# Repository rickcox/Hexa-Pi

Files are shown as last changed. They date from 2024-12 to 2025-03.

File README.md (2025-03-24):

# Hexa-Pi
A Compact 6 Compute Module Cluster

This is a PCB based project to create a very compact cluster of
Raspberry Pi CM4 compatible compute module boards.  It is quite bare-bones
in terms of peripheral support.  One of the modules - Module 5 - has a basic set of peripherals.
The other Modules - 0-4 - have only a small external connector for all I/O.
All 6 modules attach to a 1Gbit ethernet switch IC, which also has 2 off-board connectors.

It should be emphasized that **Compact Compute Cluster** is the focus of this design, not connectivity.
Connectivity, and peripheral support, has been reduced to meet the compact compute cluster goal.
Since all low voltage power, and the ethernet switch are on-board, a cluster of 6 Compute modules
can be supported with 1 12V DC power jack and 1 ethernet cable.
A 6 amp or larger 12V supply is recommended to support 6 running modules.

In addition, there are 2 external ethernet switch connectors, allowing boards to be "daisy chained".

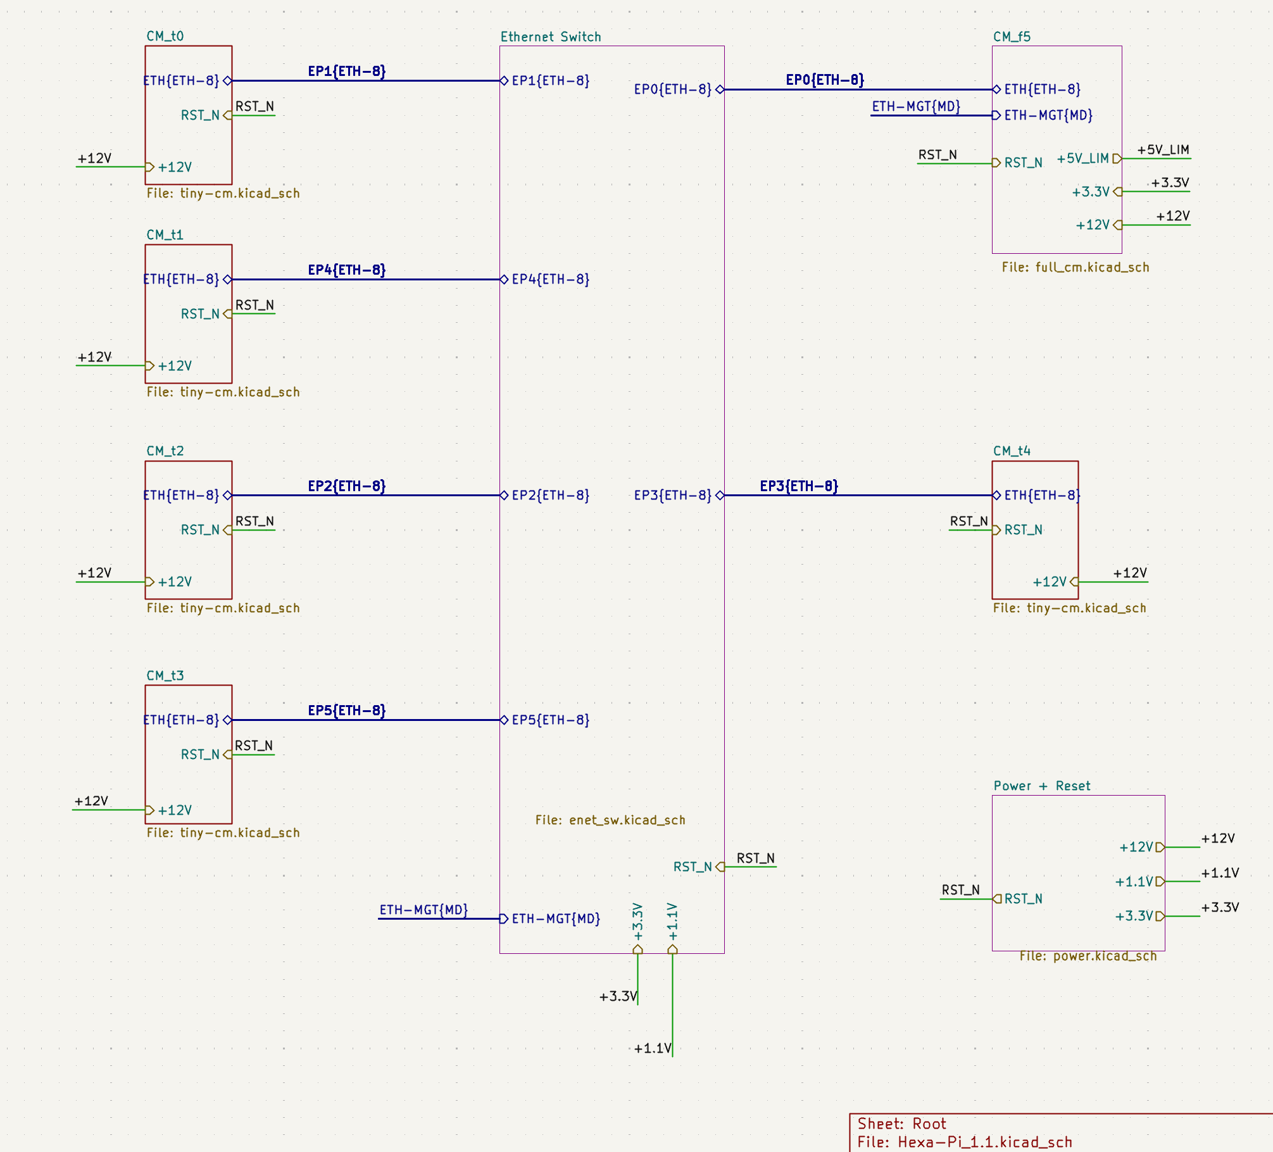
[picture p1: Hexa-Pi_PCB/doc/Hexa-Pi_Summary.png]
A simple overview


The PCB is 150mm X 150mm X 1.6mm.  

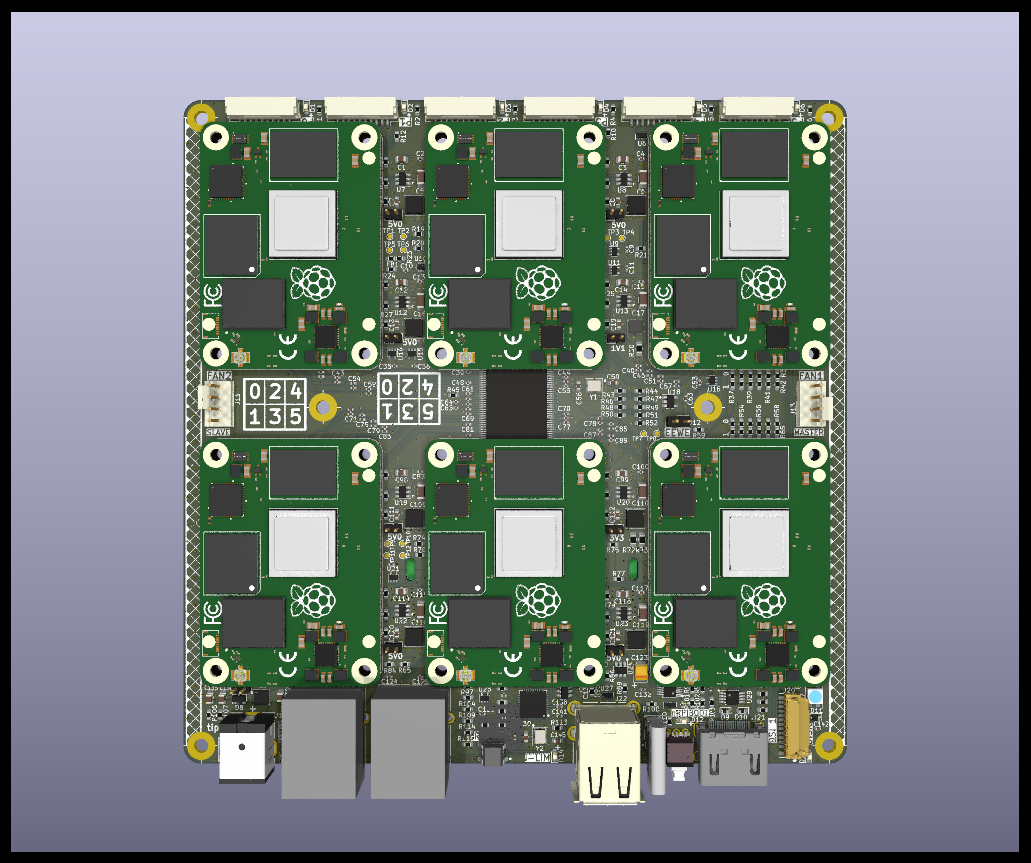
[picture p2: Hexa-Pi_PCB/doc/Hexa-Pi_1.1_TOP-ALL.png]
A View of the Hexa-Pi Board with 6 Pi CM4's installed


A goal of this design is to be as Compute Module independent as possible, to allow
for a variety of compatible modules to be used.  Several of the Compute Module compatible
boards have been tested:

- Raspberry Pi Compute Module 4:
  This board basically defigned the standard, so everything possible works on a Pi CM4.
  CM4 boards in the Module5 location may be either "Lite" or with EMMC.
  CM4 boards in the Module0-4 locations must have EMMC.
  
- Pine64 SOQuartz:
  This RK3566 base board works well. 
  Rockchip processors for some odd reason must use 1.5Mbps on the serial console.  
  The pluggable EMMC modules makes setup of these boards very easy if you buy a cheap EMMC-microSD converter.

- Banana Pi CM4:
  This Amlogic A311D based board is a bit faster than the Raspberry Pi CM4.
  These are a bit fussy to get setup, and OS selection is quite limited.

- Radxa CM5:
  This RK3588 based board is **very** fast, if that is what you are looking for.
  There are "Lite" and "Full" versions of this board. Only he Full has been tested, but both should work.
  Use caution that the extra 3rd connector does not make contact with the Hexa-Pi PCB components.
  Again, Rockchip processors use 1.5Mbps on the serial console.
  OS selection is also limited here.
  Due to higher power consumption, a larger heatsink is recommended for the Radxa CM5.

- Raspberry Pi Compute Module 5:
  **Testing TBD.**
  Not sure if serial port will work.
  The CM5 fan support is not compatible with CM4 or Hexa-Pi. The I2C fan controller can be used,
  as with a CM4

- Due to higher power consumption, a larger heatsink and possibly a heatspreader is recommended for the Raspberry Pi CM5.

Not all "compatible" boards have been tested.  
It is expected, unless the manufacturer has done something specific to make it incompatible, most "compatible" boards should work. 
Reviewing the datasheet and pinout on the 100 pin mezzanine connectors can be useful in spotting incompatibilities.

The Raspberry Pi CM4 boards have been most throughly tested.  
The other boards all have been verified to operate and connect via etherent, but all of the ports have not been tested.
Where known, incompatibilities have been noted.
It is recommended to initially configure an unfamiliar Compute Module in a Raspberry Pi CM4 IO board,
or board vendor specific baseboard, where all of the IO ports are available.
The Module5 location on the Hexa-Pi board may work for this, since it has USB, HDMI, and microSD
card support - but does not have the 40pin IO connector. 
Having a GUI is often helpful for the initial OS setup on a new board - even if your eventual use is headless.

Also, there is a small "Pi-Panel" support board that attaches to the external connectors 
at the top to provide a few simple peripherals for **all** of the Modules individually. 
A Green activity LED for each module is visible at the top, next to that module's connector.

There are also a Red power LED, a Yellow USB Overload LED, a White rpibboot mode LED, and a Blue NVME activity LED,
all on the main PCB, bottom edge.

Also included is stl files for a case for the Hexa-Pi board.
The PCB's were built, and mostly assembled, by JLCPCB.
The Case was 3D Printed. 

There is more information in the sub-directories:

- Main Hexa-Pi PCB
- Case for Hexa-Pi
- Pi-Panel PCB

This work is licensed under the Creative Commons Attribution 4.0 International License. To view a copy of the license, visit https://creativecommons.org/licenses/by/4.0/

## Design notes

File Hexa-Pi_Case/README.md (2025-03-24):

# Hexa-Pi
A Case for the Hexa-Pi board.

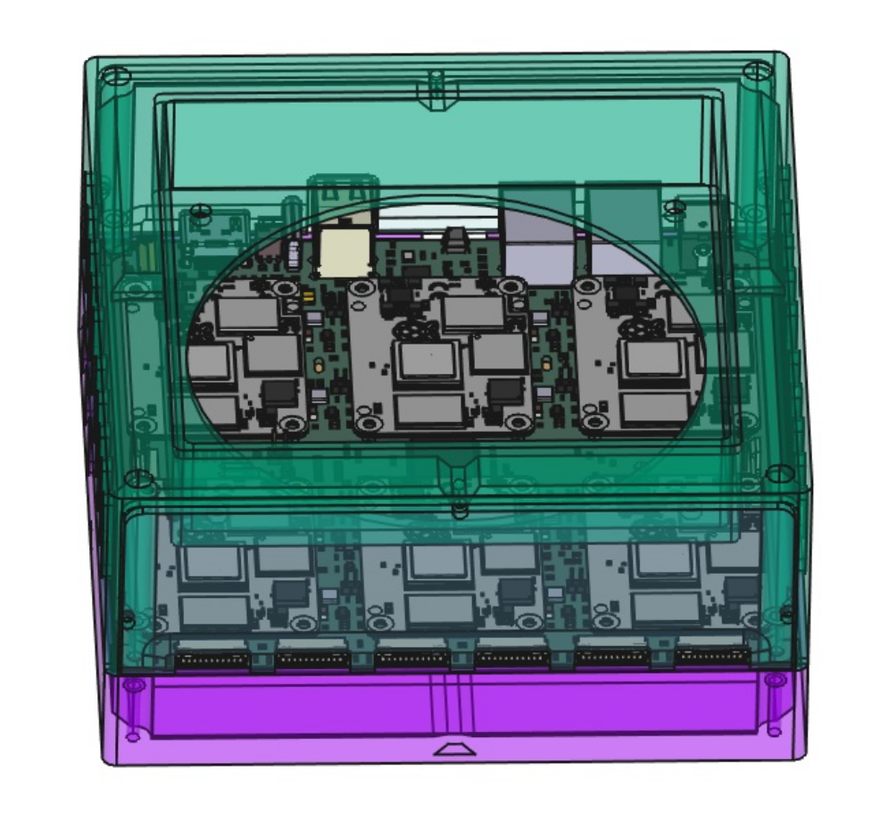
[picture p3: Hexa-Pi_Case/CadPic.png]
CAD Picture


Cases Stacked:

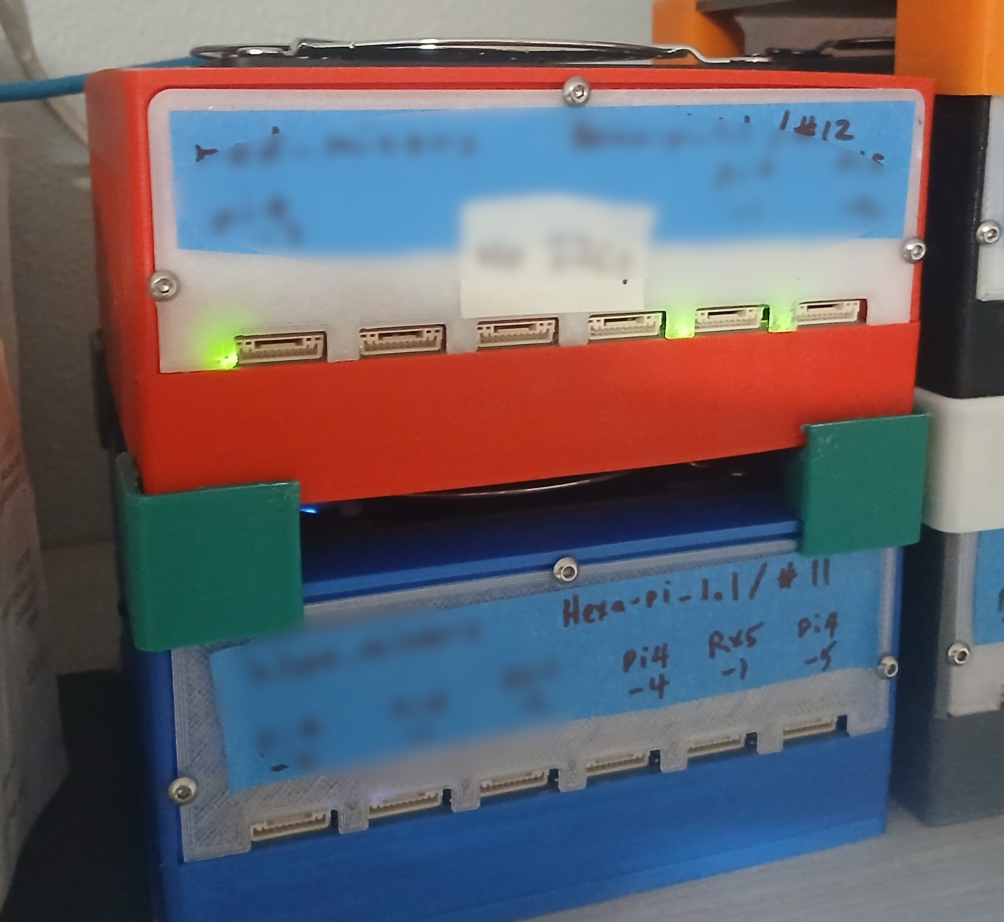
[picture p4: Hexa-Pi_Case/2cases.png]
Stacked Picture


This is a fairly simple case for the Hexa-Pi board.
It consists of 4 parts:
- A bottom
- A top - with the PCB connector ends fully exposed
- A Front Panel - this has cutouts for the 6 external connectors
  It is recommended to make this out of semitransparent material so the
  LEDS are readily visible
- A Back Panel - This has cutouts for the power, ethernet, USB and HDMI connectors.
  It is recommended to make this out of semi-transparent material so the
  LEDS are readily visible

In addition, there is a small standOff. 4 of these can be used for stacking.

For good airflow, a 120MM fan is inset on the top, and ventilation slots are on the sides.
The top fan location makes the case larger but provides good airflow without alot of sound,
and allows stacking of Hexa-Pi's. 
120MM fans can be run at around 1/2 speed, and still provide adequate cooling.

Additional hardware needed to assemble 1 board and case:
- 6 M3 heatset fittings. These are heat-set into the bottom - 2 near the center to
  hold the PCB from flexing, and 4 on the corners to secure the top.
- 6 10MM M3 bolts - 2 to hold the PCB, and 4 to secure the case top to the PCB and bottom
  Hex head bolts rather than Phillips head is preferred, since they are deeply inset.
  The 4 corners are difficult to access due to being deeply inset - SORRY!
- 6 4MM M3 bolts or tapered screws to hold the front and back panels on.
  These interfere with, and must be installed after (and removed before) the M3 corner bolts.
- A 120MM X 120MM fan with a 4 pin PWM connector.
  A fan which includes a finger guard/screen is recommended for safety.
  If the fan has a long lead, either wrap it around the fan side or zip-tie to the case.
- M5 bolts are usually provided with fans to hold the fan in place.
  Insert these bolts from inside the case and thread into the fan housing before assembling the case.

The long, deeply inset corner screws are very clumbsy to work with.
They make the case time consuming to assemble and dis-assemble.
Also the attachment of the front and back panels could be greatly improved.
**I would love some sort of snap on case, but my mechanical CAD skills are not there yet!**
**HINT, HINT!**

This work is licensed under the Creative Commons Attribution 4.0 International License. To view a copy of the license, visit https://creativecommons.org/licenses/by/4.0/

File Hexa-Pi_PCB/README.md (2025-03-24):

# Hexa-Pi_PCB
A Compact 6 Compute Module Cluster PCB

Here are some views of the PCB.
More are available in the doc folder.

Top view of PCB
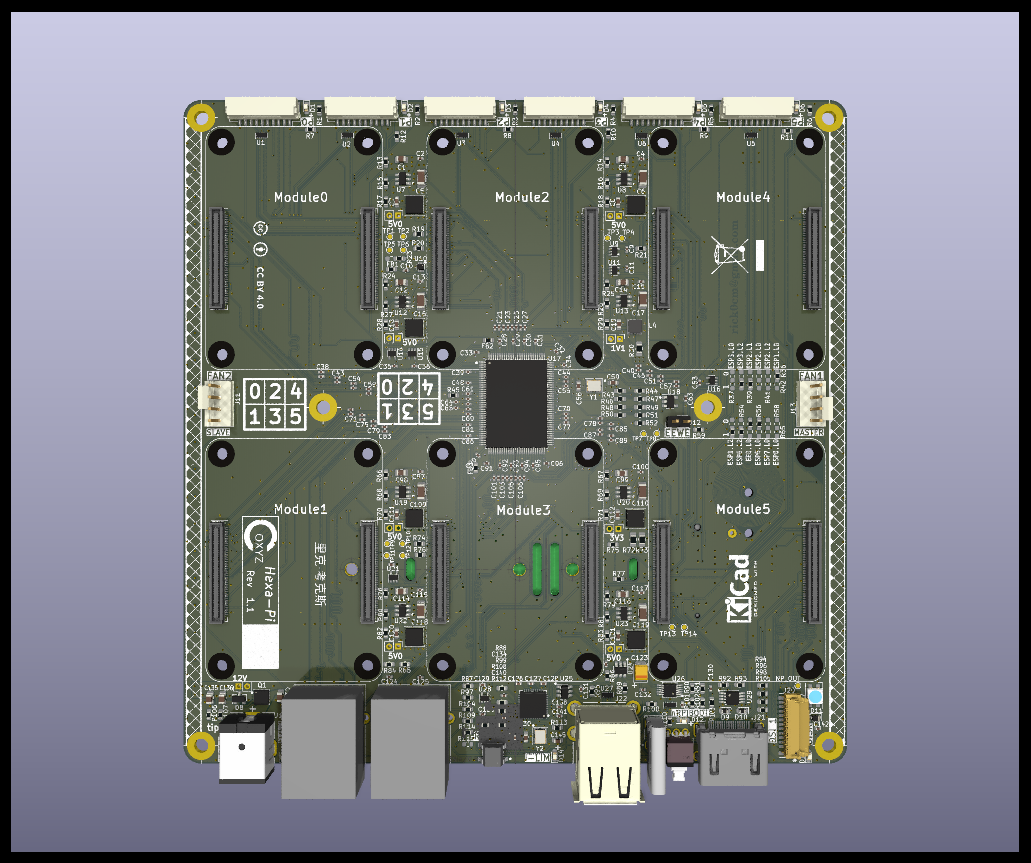
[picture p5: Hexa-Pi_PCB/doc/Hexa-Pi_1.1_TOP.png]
Top View
.

Bottom view of PCB
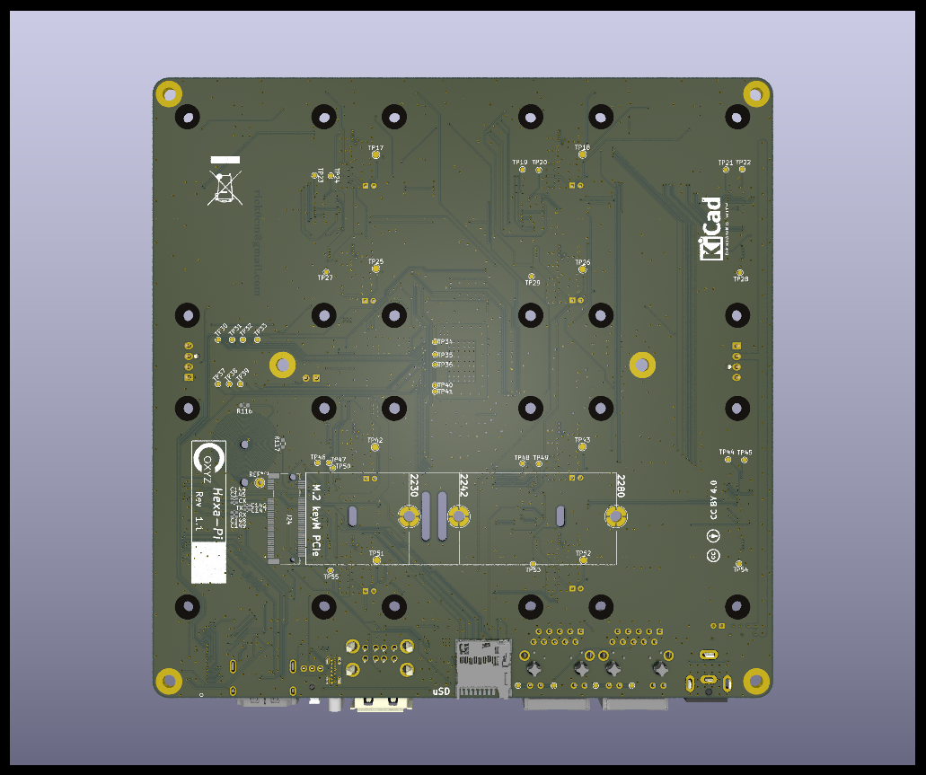
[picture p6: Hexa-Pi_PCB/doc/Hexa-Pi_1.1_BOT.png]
Bottom View
.

Dimensions of PCB
Dimension View.
Note that the PCB is 1.6MM thick.

The PCB is intended to be mounted with the top and bottom edges exposed, since there are used connectors and LEDS there.
Along the top edge are the 6 External Connectors, and 6 Activity LEDS  - one for each Module.

Along the bottom - left to right are:
- Power in - nominally 12V. This is a standard size 5.5X2.5MM DC Barrel jack - Center positive.
  This voltage is used directly for the fan, so a 12V fan is required.
  If the fan is not considered, the on board power regulators should work with from 8V to 15V.
  A 6 amp or larger 12V supply is recommended to support 6 running modules.
- Red Power on LED.  "The board is HOT".
- 2 ethernet jacks. These are attached to the on-board switch, so may be used independently.
- A reset switch. Resets everything - all Compute modules and the switch.
- On the bottom is a microSD card slot. This is attached to Compute Module 5.
  On a Raspberry Pi Compute Module, this is only usable on Lite CM's - those without EMMC.
- Yellow USB (and HDMI) overcurrent alert.  This lights up if the current limiter kicks on.
- Dual USB-A ports.  These are attached to Compute Module 5.
  The power budget on this board is slim and USB current draw is limited.  
  THIS IS NOT A CHARGING PORT!!  Keep current draw on the USB ports to < 500 ma, or you will undervolt Module 5.
- USB-C connector.  This is used when accessing the Compute Mmdule 5's EMMC in rpiBoot mode.
- rpiBoot switch and White LED.  Push the locking switch before booting into rpiBoot mode.
  Push again to release into normal mode.
  The LED is on to confirm the locking switch is activated.
- Full sized HDMI connector.  Attached to Compute Module 5.
- Standard Raspberry Pi DSI Display connector. Attached to Compute Module 5.
- Blue PCIe DISK activity LED.
- Behind the DISK LED is a neoPixel connected to Compute Module 5 GPIO 18.

At the right center is the Master fan connector - Fan1.
This should be used first is multiple fans are used.
At the left center is the Slave fan connector - Fan2.
Both fan connectors are standard 4 pin PWM fan connectors.
A single fan EMC2301 controller drives both fan connectors.
The "tach" from Fan1 can be used by the fan controller to send PWM signals to both fans.
Both fans should run at the same PWM controlled speed, but the controller only sees the speed of Fan1.
This controller sits on the I2C bus attached to Compute Module 5.

A **WARNING** note on the fans. The EMC2301 fan controller has shown it is **VERY**
sensitive to emc, so **never** plug or unplug fans while the board is powered, or fans spinning.
Numerous fan controllers had to be replaced during Hexa-Pi board testing discovering this limitation!

Also on the bottom, not on the board edge, is an M.2 "Key M" slot for an NVMe.
2230, 2242, and 2280 sized M.2 cards are supported.
A soldered or bolted holddown is required at the appropriate location.
Use **caution** - there is the possibility of interference with 2 of the messanine
connectors on the top side of some holddowns. Test the clearance before powering on to avoid smoke.
The M.2 is attached to the PCIe bus on Compute Module 5.
Any M.2 Key M card which fits should work - at least in hardware.

There are 6 M3 mounting holes - 2 near the center, and 4 at the corners.
If you use the supplied 3D printed case, the center 2 holes hold the PCB down, and the outer 4 holes
hold the case together.

The 6 Compute Module sites are marked nad outlined.
Note that the Mezzanine connectors are **not** symmetric, so the CM orientation matters.
The Module numbering is consistent between the actual board mounting locations and the 
Activity LED/External connectors at the top. (Module 0 -> P0, Module 1 -> P1, etc..)
Some of the non-Raspberry Pi modules have an extra 3rd messanine connector which is a no-connect, so watch out for interference in this case.  
There should be enough vertical clearance to handle the extra messanine, but **verify** before powering on.

M2.5 CM holdown mounting holes are provided at each CM's corners, but should not needed for most cases.

**Power Consumption TBD**

This work is licensed under the Creative Commons Attribution 4.0 International License. To view a copy of the license, visit https://creativecommons.org/licenses/by/4.0/

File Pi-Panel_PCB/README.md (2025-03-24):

# Pi-Panel
A small "Front Panel" for the compute modules in the Hexa-Pi PCB.
5 of the modules have no other peripherals other than ethernet.

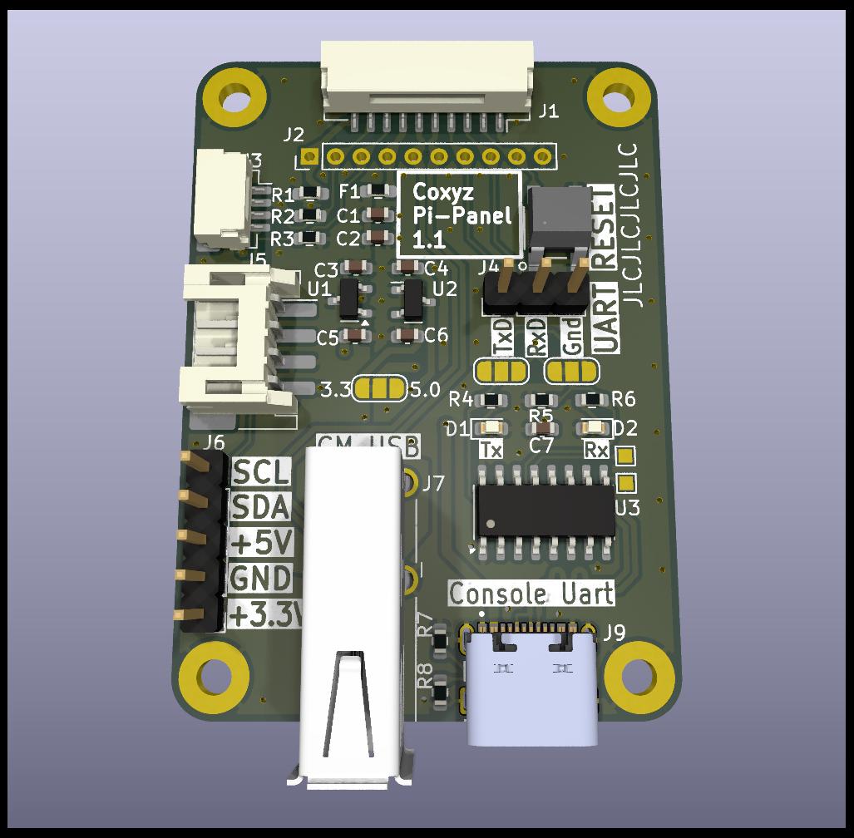
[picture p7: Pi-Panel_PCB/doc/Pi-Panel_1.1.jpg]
the Pi-Panel PCB


This is a small 36mm X 50mm PCB based that connects to the main Hexa-Pi board
using a 10 wire interface with JST connectors.

Since the individual Compute Modules on the main PCB are all powered together,
the goal with this board is to allow some basic repair and diagnosis if here are errors 
or failures on specific modules - without powering the main board down and disassembling the case!

The Activity LED for each module is adjacent and to the left of that board's conncetor.
The panel provides for each module individually:
- 5V and Gnd. Realistically about 500ma MAX can be pulled from 5V.
  **Warning** this is NOT current limited. 
  If you overload it, you will undervolt that Compute Module
- A Reset Push-Button for that specific CM.
- A serial console and CH340C USB to serial converter.
  You can directly plug into the USB-C connector and see a serial port.
  This connection uses the Raspberry 4 Compute Module serial interface pins -
  GPIO 14 (RxD) and GPIO 15(RxD). NOTE - some of the non-Raspberry Pi
  Compute modules default to different Serial console ports&pins
- A USB 2.0 port. This may be used to add any normal usb peripheral to the Pi.
  A USB Flash drive is the obvious usage, but anything USB2 compatible should work.
- An I2C port. This can be used for whatever desired.  
  This was initially envisioned as some sort of external display and maybe a couple
  buttons to control it.  Nothing has been developed here though, but
  there may be some interesting off-the-shelf options out there.
  The I2C is available on 3 Pi-Panel connectors:
  - A QWIIC Connector.
  - A Stemma-QT Style connector.
  - 0.1 inch headers.  Included is a 3.3V supply, which may be useful in some situations.
    This is a 250ma LDO off of the 5V supply, so remember the current **warning** above.

The connection to the main Hexa-Pi board uses a 10 pin JST GH 1.25mm connector.
Manufacturer partnumber SM10B-GHS-TB.  It is possible to buy pre-assembeled cables
with this mating connector. They can be purchased with connectors on both ends, or
having 1 end free.  Look for something like "GH 1.25MM 10P Single Ended" or "Double Ended".  
There are solderable holes on the Pi-Panel so the "Single Ended" type cable assemblies can be used,
and hand soldered on the Pi-Panel end.

Oh, and **one ugly secret!** The 10 pin JST connectors used between the Panel and main Hexa-Pi
board do not support any type of sequencing (Connect ground before anything else).
As a result, plugging the Pi-Panel into a running Hexa-Pi **MAY** result in the
connected Compute Module spontaneously resetting.  Being careful to have the Panel
grounded before plugging it in seems to minimize this anomaly!  
If another version of this board is done, this is on the list of things to try and fix, 
but you need to live with it for now.

This was developed in KiCad, and the design files are here.
The initial PCB's were built by JLCPCB, and partially assembled by them.
The through-hole parts and I2C connectors were hand assembled.

This PCB was small enough, that a panel of 2 was actually build.
Directory **production** has the 1 instance manufacturing data, and
directory **production-pnl** has the 2 instance manufacturing data.
At JLCPCB, both PCB's cost the same, since they are under 50mmX50mm.
The assembled 2 instance panel costs slightly more due
to the incremental cost of the parts - but you get 2 boards for the price of 1!

This work is licensed under the Creative Commons Attribution 4.0 International License. To view a copy of the license, visit https://creativecommons.org/licenses/by/4.0/

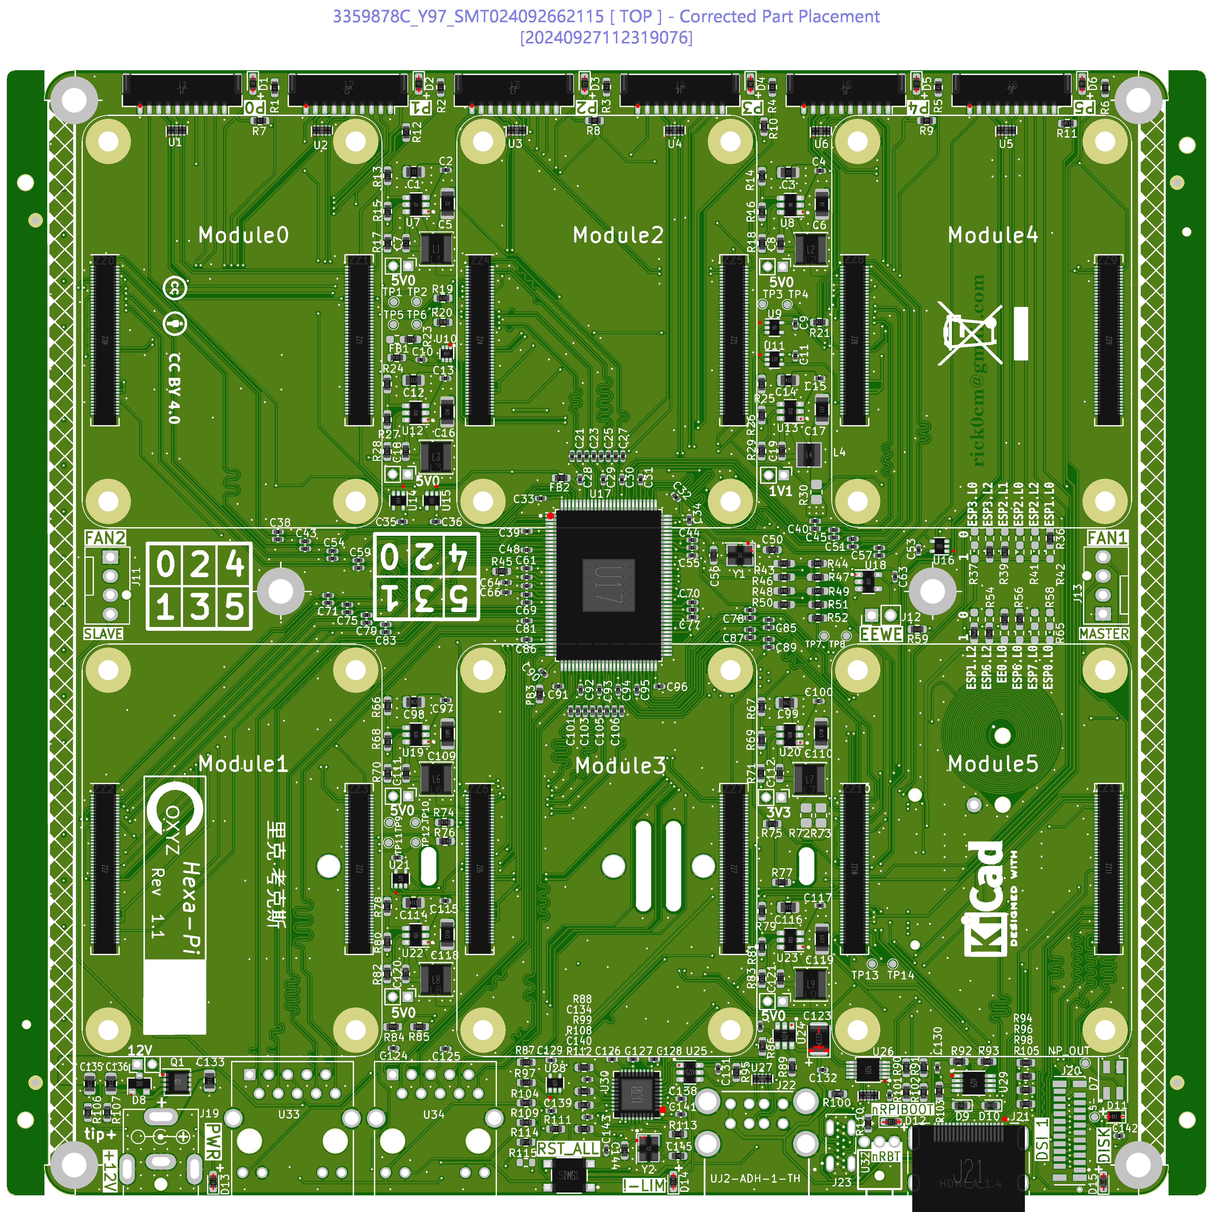
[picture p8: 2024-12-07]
Hexa-Pi_PCB/doc/Hexa-Pi_1.1-Produce_DanZhi.SMT_Snapshot.Top.3359878C_Y97.SMT024092662115.png

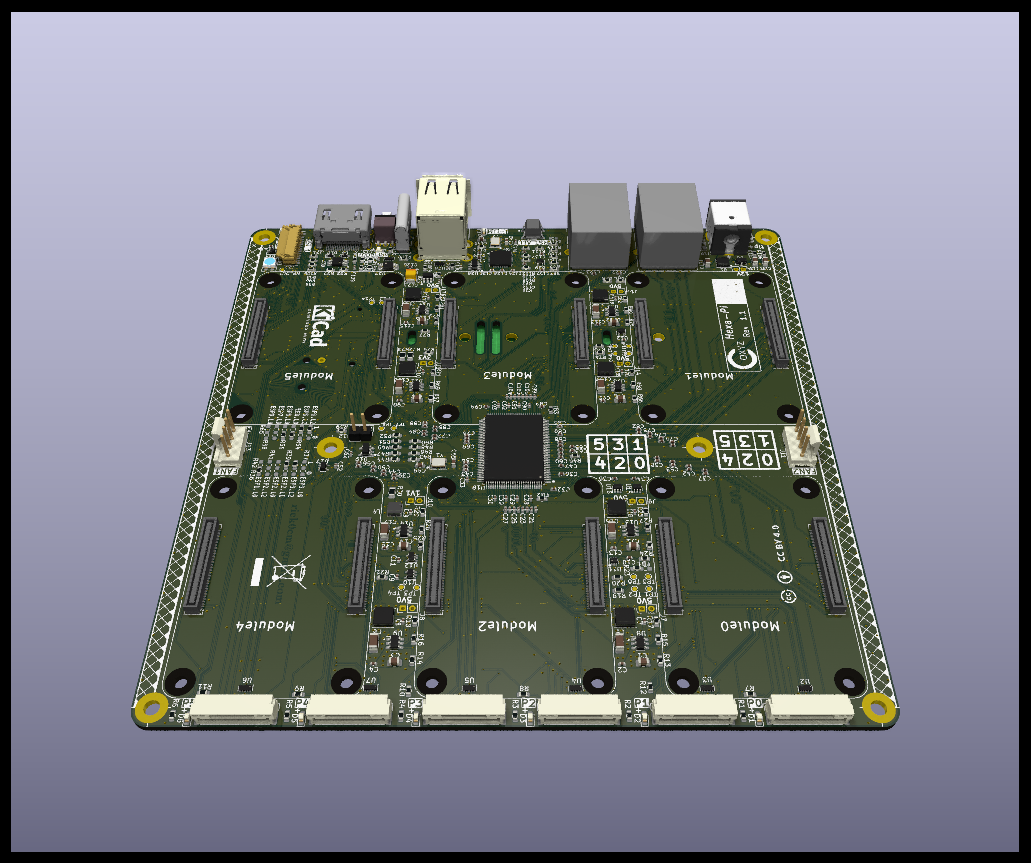
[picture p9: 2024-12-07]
Hexa-Pi_PCB/doc/Hexa-Pi_1.1_BACK.png

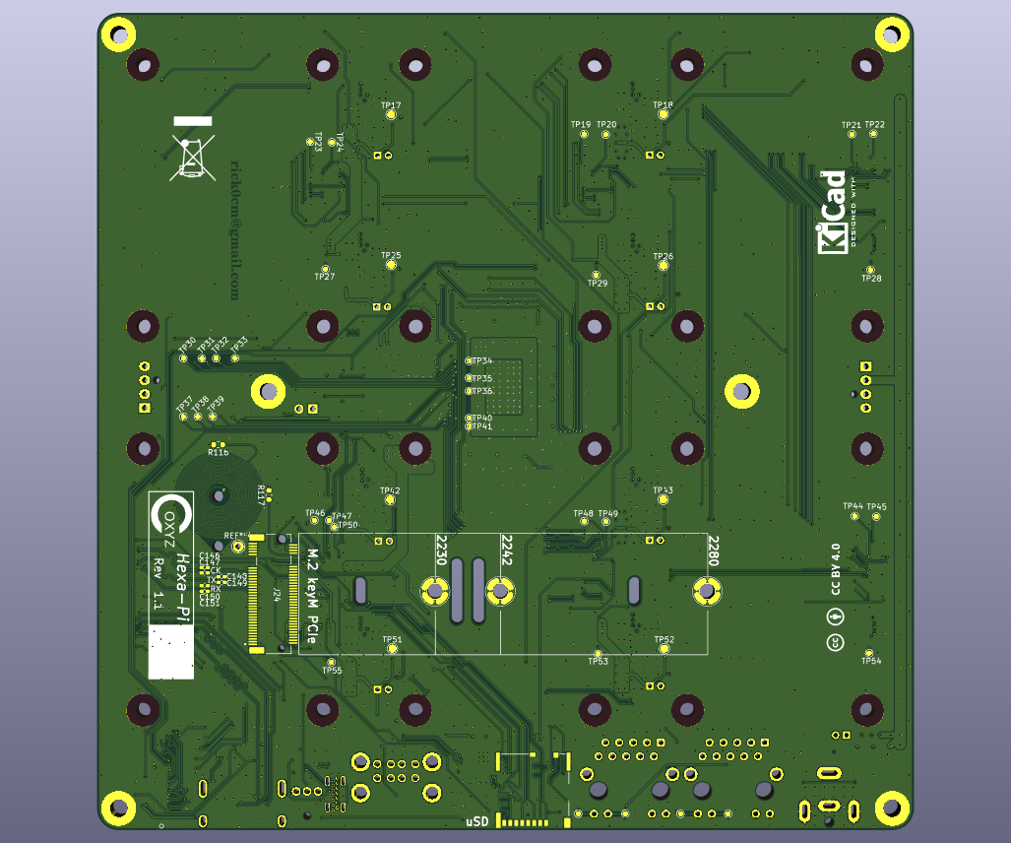
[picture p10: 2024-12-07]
Hexa-Pi_PCB/doc/Hexa-Pi_1.1_BARE_BOT.png

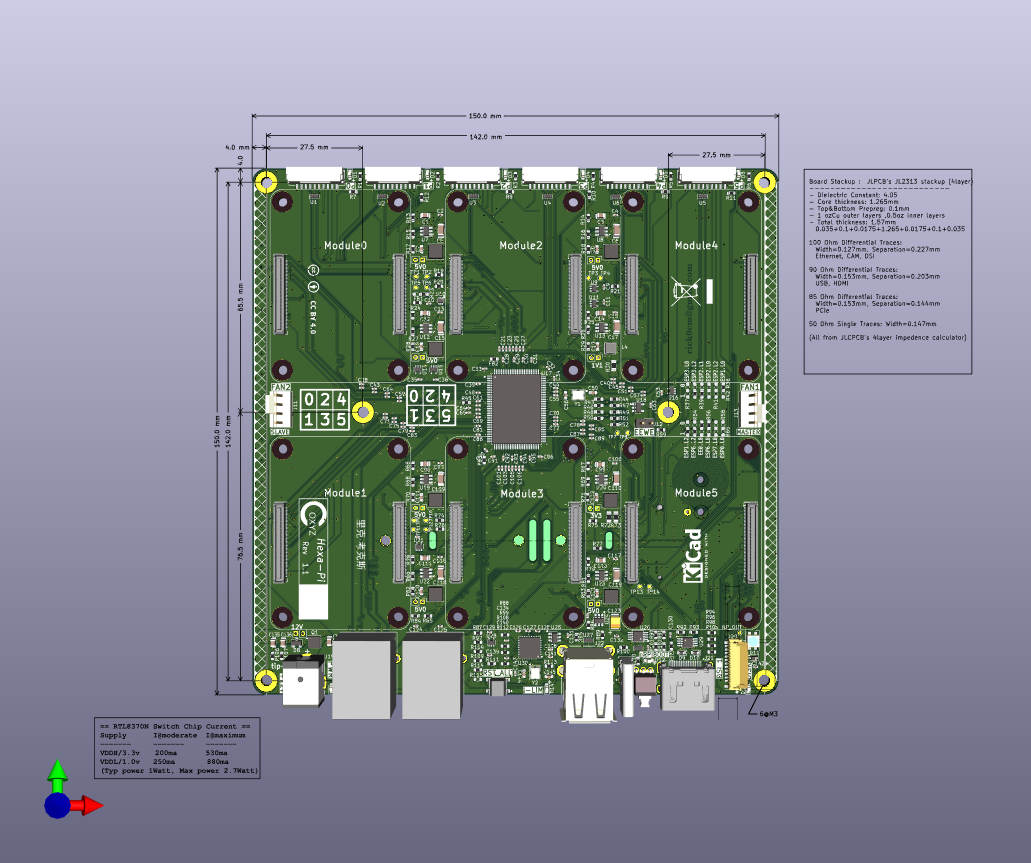
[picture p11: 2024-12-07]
Hexa-Pi_PCB/doc/Hexa-Pi_1.1-DIMENSIONS.png

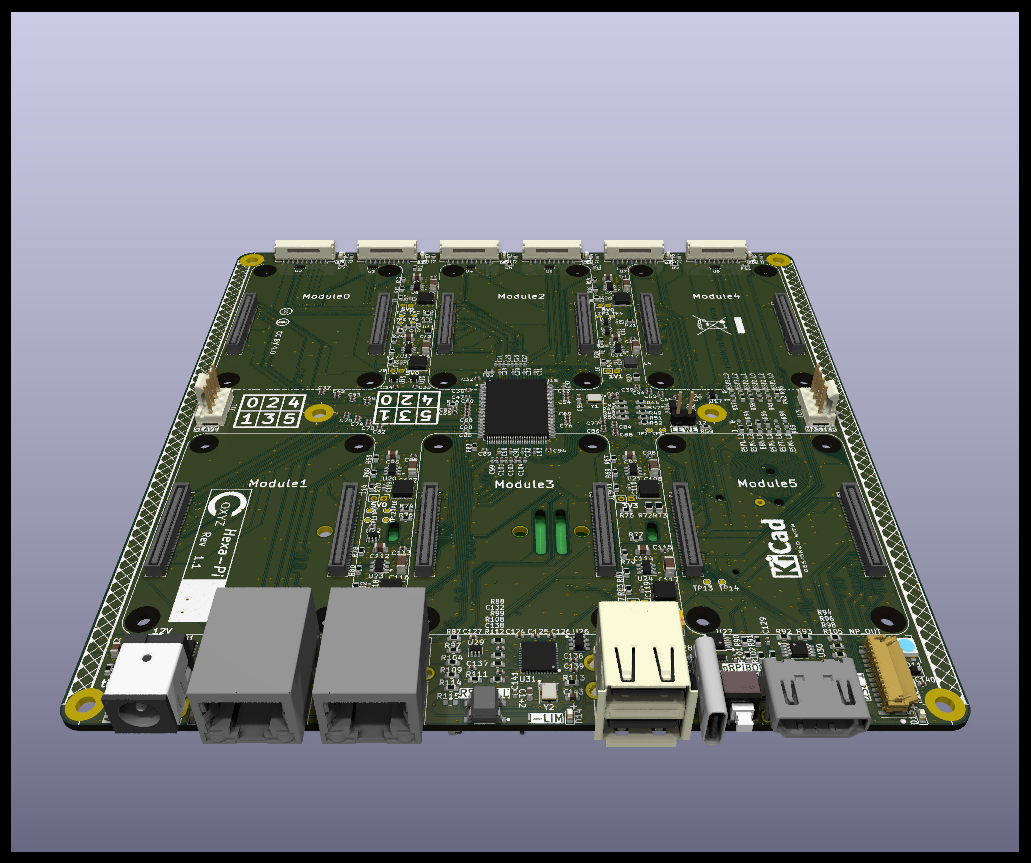
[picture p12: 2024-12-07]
Hexa-Pi_PCB/doc/Hexa-Pi_1.1_FRONT.png

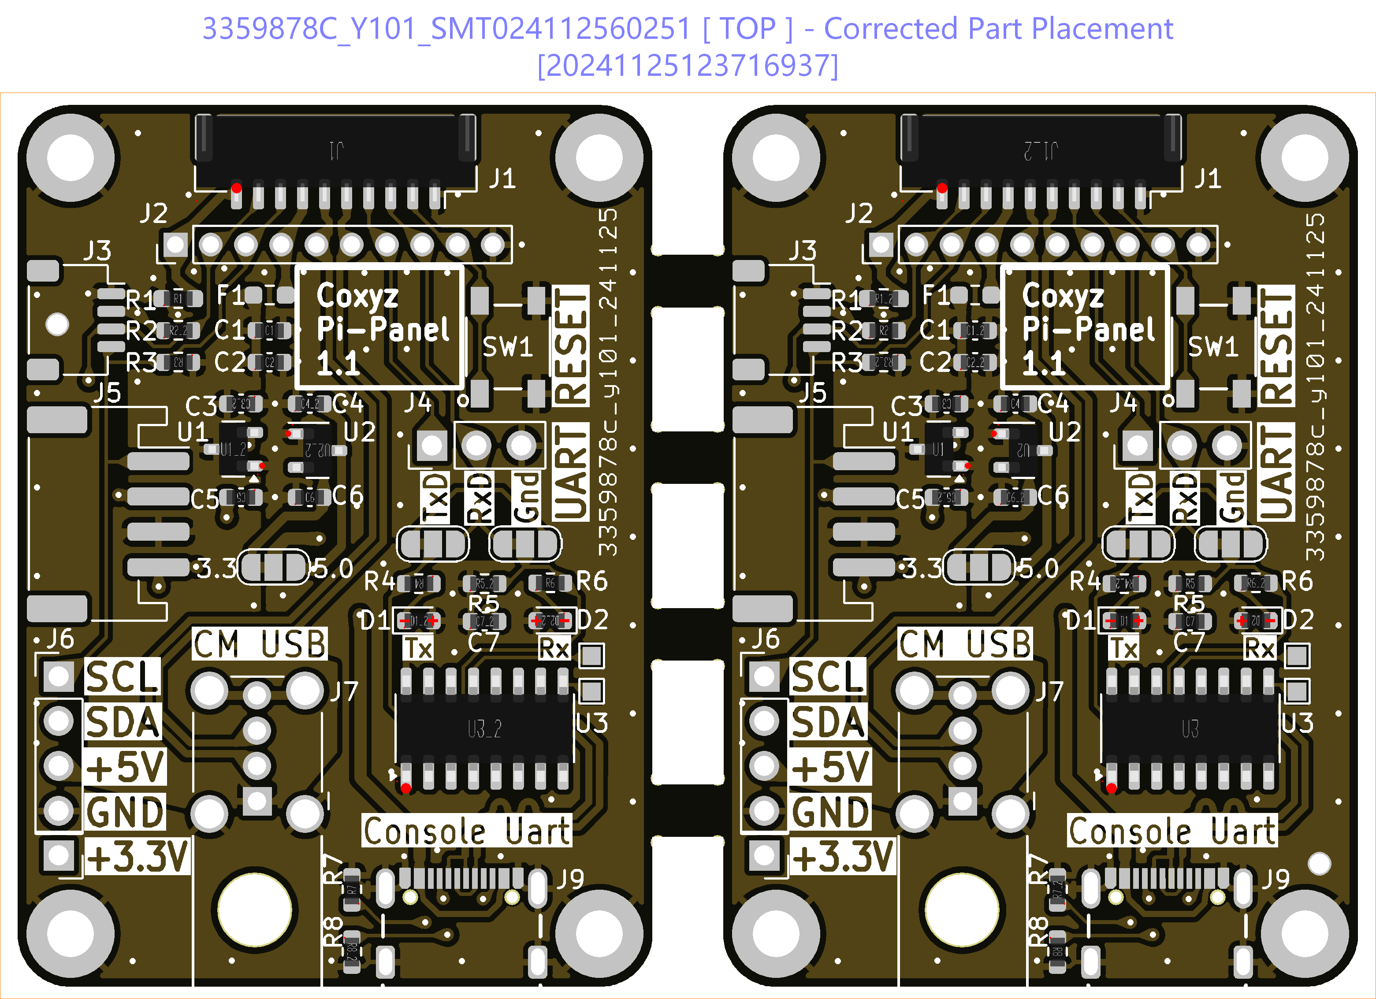
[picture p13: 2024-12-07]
Pi-Panel_PCB/doc/46623155425280-Produce_DanZhi.SMT_Snapshot.Top.3359878C_Y101.SMT024112560251.png

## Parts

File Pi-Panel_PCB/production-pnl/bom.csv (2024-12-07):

Designator | Footprint | Quantity | Value | LCSC Part #
C1_2, C1 | 0603 | 2 | 10u | C19702
C2_2, C2, C7_2, C7 | 0603 | 4 | 100n | C14663
C3_2, C3, C4_2, C4 | 0603 | 4 | 1u | C15849
C5_2, C5, C6_2, C6 | 0603 | 4 | 2.2u | C23630
D1_2, D1 | 0603 | 2 | LED_RED | C2286
D2_2, D2 | 0603 | 2 | LED_GREEN | C72038
F1_2, F1 | 0603 | 2 | Fuse_0.5A | C2960491
J1_2, J1 | JST_GH_SM10B-GHS-TB_1x10-1MP_P1.25mm_Horizontal | 2 | Conn_01x10 | C2683602
J3_2, J3 | JST_SH_SM04B-SRSS-TB_1x04-1MP_P1.00mm_Horizontal | 2 | STEMMA-QT | C160404
J5_2, J5 | JST_PH_S4B-PH-SM4-TB_1x04-1MP_P2.00mm_Horizontal | 2 | STEMMA | C265102
J9_2, J9 | GCT_USB4105-GF-A | 2 | USB4105-GF-A | C5184243
R1_2, R1 | 0603 | 2 | 0R | C21189
R2_2, R2, R3_2, R3 | 0603 | 4 | 10K | C25804
R4_2, R4, R6_2, R6 | 0603 | 4 | 1K2 | C22765
R5_2, R5 | 0603 | 2 | 33k | C4216
R7_2, R7, R8_2, R8 | 0603 | 4 | 5K1 | C23186
SW1_2, SW1 | pushButton-PTS647SM38SMTR2LFS | 2 | pushButton-PTS647SM38SMTR2LFS | C2689502
U1_2, U1, U2_2, U2 | SOT-23 | 4 | APE8865N-33-HF-3 | C296288
U3_2, U3 | SOIC-16_3.9x9.9mm_P1.27mm | 2 | CH340C | C7464026

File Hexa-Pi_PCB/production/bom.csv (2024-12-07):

Designator | Footprint | Quantity | Value | LCSC Part #
C1, C114, C116, C12, C135, C14, C3, C98, C99 | 0805 | 9 | 10u 25V | C440198
C10, C100, C101, C102, C103, C104, C105, C106, C107, C108, C11, C113, C115, C117, C122, C124, C125, C126, C128, C129, C13, C130, C132, C134, C137, C138, C139, C140, C141, C142, C15, C2, C20, C21, C22, C23, C24, C25, C26, C27, C28, C29, C30, C31, C33, C34, C35, C36, C37, C38, C39, C4, C40, C41, C42, C43, C44, C45, C46, C47, C48, C49, C51, C52, C53, C54, C55, C57, C58, C59, C60, C61, C62, C63, C64, C65, C66, C67, C68, C69, C70, C71, C72, C73, C74, C75, C76, C77, C78, C79, C80, C81, C82, C83, C84, C85, C86, C87, C88, C89, C9, C91, C92, C93, C94, C95, C96, C97 | 0402 | 108 | 100n | C1525
C109, C110, C118, C119, C16, C17, C5, C6 | 1206 | 8 | 47u 10V | C96123
C111, C112, C120, C121, C18, C19, C7, C8 | 0603 | 8 | 100n | C14663
C123 | CP_EIA-3528-21_Kemet-B | 1 | 100u | C16133
C127, C131, C143, C32, C90 | 0402 | 5 | 10u | C15525
C133, C136 | 0805 | 2 | 100n 100v | C28233
C144, C145 | 0603 | 2 | 20p | C1648
C50, C56 | 0603 | 2 | 12p | C38523
D1, D2, D3, D4, D5, D6 | 0603 | 6 | LED_GREEN | C965805
D10, D9 | 0603 | 2 | BESDU0603-05 | C512307
D11 | D_SOD-323 | 1 | 1N5819 | C2828425
D12 | 0603 | 1 | LED_WHITE | C2290
D13 | 0603 | 1 | LED_RED | C2286
D14 | 0603 | 1 | LED_YELLOW | C72038
D15 | 0603 | 1 | LED_BLUE | C19171394
D7 | LED_SK6812MINI_PLCC4_3.5x3.5mm_P1.75mm | 1 | WS8212B-MINI | C527089
D8 | D_SOT-23_ANK | 1 | MMBZ5242BLT3G | C112551
FB1, FB2, FB3 | 0603 | 3 | FerriteBead_Small | C1002
J1, J2, J3, J4, J5, J6 | JST_GH_SM10B-GHS-TB_1x10-1MP_P1.25mm_Horizontal | 6 | Conn_01x10 | C2683602
J11, J13 | FanPinHeader_1x04_P2.54mm_Vertical | 2 | Molex Fan Header | C240840
J12 | PinHeader_1x02_P2.54mm_Vertical | 1 | EEWE | C7501580
J19 | CUI_PJ-063AH | 1 | Barrel_Jack_HC | NA
J20 | Hirose_FH12-22S-0.5SV55_P0.5mm_Vertical | 1 | Conn_01x22_Female | NA
J21 | EDAC 690-019-298-412 | 1 | HDMI_A_1.4 | C720616
J22 | MOLEX_USB_67298-4090 | 1 | UJ2-ADH-1-TH | C12049
J23 | Molex-216989-0001-MFG | 1 | 216989-0001 | NA
J24 | JAE_SM3ZS067U310AMR1200 | 1 | SM3ZS067U310AMR1200 | C4527433
J25 | SDCARD_MOLEX_503398-1892 | 1 | Micro_SD_Card_Det | C428492
L1, L2, L3, L6, L7, L8, L9 | L_Changjiang_FNR4012S | 7 | 4020-3R3 | C602030
L4 | L_Wuerth_MAPI-3012 | 1 | 3012-1R5 | C5127315
Q1 | Diodes_PowerDI3333-8 | 1 | DMP3013SFV-7 | C264098
R1, R110, R111, R19, R2, R20, R21, R3, R4, R5, R52, R59, R6, R74, R76, R94 | 0603 | 16 | 1K2 | C22765
R10, R11, R12, R13, R14, R24, R25, R66, R67, R7, R78, R79, R8, R9 | 0603 | 14 | 10K | C25804
R100, R102, R106 | 0603 | 3 | 5K1 | C23186
R101, R90 | 0603 | 2 | 2K2 | C4190
R103, R108, R112, R77, R88, R89, R95, R99 | 0603 | 8 | 39K | C23153
R104, R91, R97 | 0603 | 3 | 510K | C23192
R105, R36, R38, R39, R44, R51, R55, R56, R60, R61, R98 | 0603 | 11 | 4K7 | C23162
R107, R113, R86 | 0603 | 3 | 12K | C22790
R109, R114, R84, R85 | 0603 | 4 | 470R | C23179
R15, R16, R27, R68, R80, R81 | 0603 | 6 | 56K2 | C227508
R17, R18, R28, R29, R70, R71, R82, R83, R87, R96 | 0603 | 10 | 22K | C31850
R23, R43, R46, R47, R48, R49, R50, R92, R93 | 0603 | 9 | 0R | C21189
R26 | 0603 | 1 | 4K5 | C364182
R30, R72, R73 | 0805 | 3 | 0R HC | C1882631
R45 | 0603 | 1 | 2K49 | C227773
R69 | 0603 | 1 | 34K | C667699
R75 | 0603 | 1 | 5R | C25197
SW1 | pushButton-PTS647SM38SMTR2LFS | 1 | pushButton-PTS647SM38SMTR2LFS | C2689502
U1, U2, U27, U3, U31, U4, U5, U6 | USON-10_2.5x1.0mm_P0.5mm | 8 | TPD4EUSB30 | C558427
U10 | SOT-563 | 1 | TMP102xxDRL | C99269
U11, U14, U15, U16, U21, U28, U9 | SOT-353_SC-70-5 | 7 | 74LVC1G07SE-7 | C7830
U12, U19, U22, U23, U7, U8 | TSOT-23-6w | 6 | TPS564201 | C464812
U13, U20 | TSOT-23-6w | 2 | AP62300TWU | C1883519
U17 | LQFP-128_14x20mm_P0.5mm_1 | 1 | RTL8370N | C2803243
U18 | SOT-23-5 | 1 | 24C04-I2C-EEPROM (512X8) | C232867
U24, U25 | SOT-23-6 | 2 | AP22653W6-7 | C2158037
U26 | MSOP-10_3x3mm_P0.5mm | 1 | FSUSB42MUX | C11355
U29 | MSOP-8_3x3mm_P0.65mm | 1 | EMC2301 | C148036
U30 | QFN-36-1EP_6x6mm_P0.5mm_EP3.7x3.7mm | 1 | USB2514B-AEZC | C16251
U32 | SW-TH_TK-6580B-1 | 1 | TK-6580B-1 | C2689829
U33, U34 | ARJM11B1-502-AB | 2 | Abracon_ARJM11B1-502-AB | C240190
Y1 | Crystal_SMD_3225-4Pin_3.2x2.5mm | 1 | 25MHZ | C9006
Y2 | Crystal_SMD_3225-4Pin_3.2x2.5mm | 1 | 24MHZ | C70571
ZZ0, ZZ1, ZZ10, ZZ11, ZZ2, ZZ3, ZZ4, ZZ5, ZZ6, ZZ7, ZZ8, ZZ9 | HRS_DF40HC(3.0)-100DS-0.4V | 12 | HRS_DF40HC_3.0_-100DS-0.4V_58

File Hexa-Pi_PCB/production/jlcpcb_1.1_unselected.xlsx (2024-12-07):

?Designator | Value | Footprint | Quantity
R30,R72,R73 | 0RHC | 0805 | 3
U32 | TK-6580B-1 | SW-TH_TK-6580B-1 | 1
J22 | UJ2-ADH-1-TH | MOLEX_USB_67298-4090 | 1
U33,U34 | Abracon_ARJM11B1-502-AB | ARJM11B1-502-AB | 2
J11,J13 | MolexFanHeader | FanPinHeader_1x04_P2.54mm_Vertical | 2
J12 | EEWE | PinHeader_1x02_P2.54mm_Vertical | 1
D7 | WS8212B-MINI | LED_SK6812MINI_PLCC4_3.5x3.5mm_P1.75mm | 1
J20 | Conn_01x22_Female | Hirose_FH12-22S-0.5SV55_P0.5mm_Vertical | 1
J23 | 216989-0001 | Molex-216989-0001-MFG | 1
J19 | Barrel_Jack_HC | CUI_PJ-063AH | 1

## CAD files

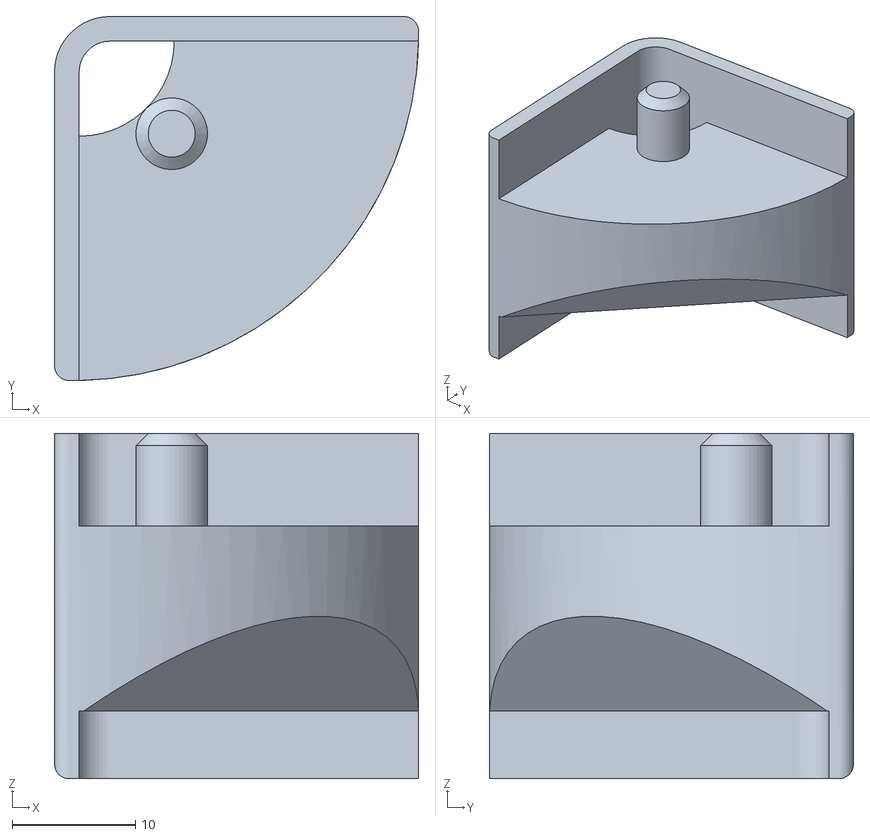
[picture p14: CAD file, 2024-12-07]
Hexa-Pi_Case/standoffBody.stl
29.5 x 29.5 x 28.0

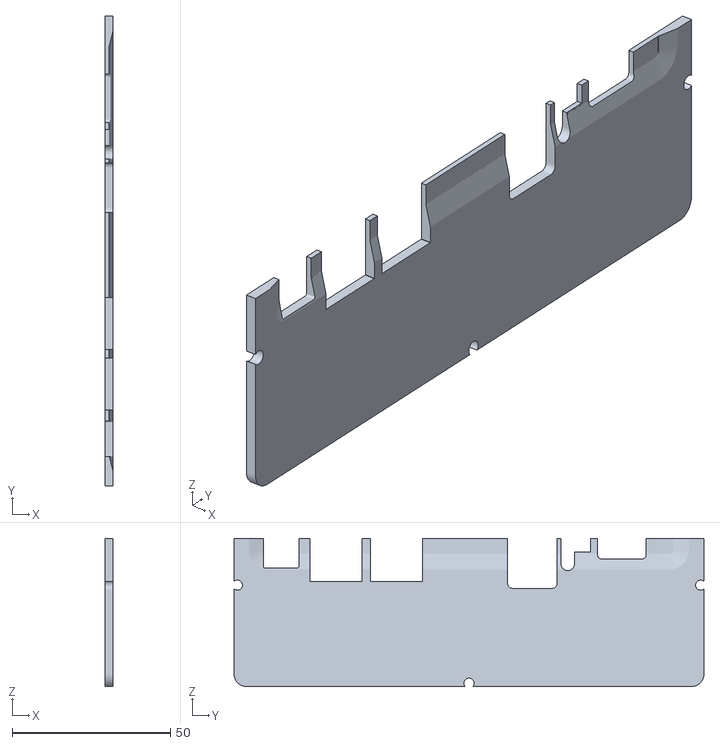
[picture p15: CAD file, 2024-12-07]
Hexa-Pi_Case/HexPi_1.1_backPanelBody.stl
2.40 x 148.5 x 46.8

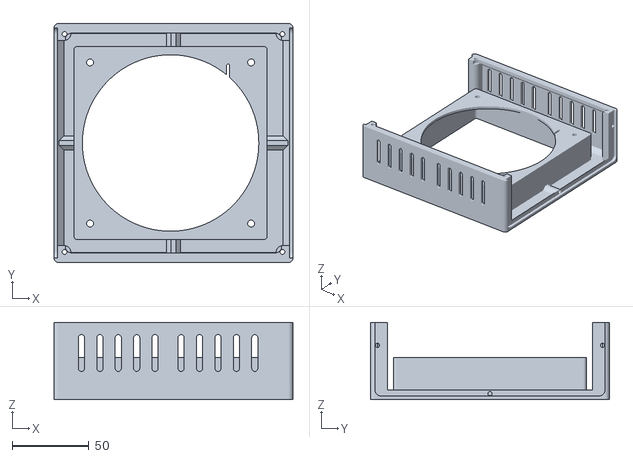
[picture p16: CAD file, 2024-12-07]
Hexa-Pi_Case/HexPi_1.1_topBody.stl
155.8 x 155.8 x 50.4

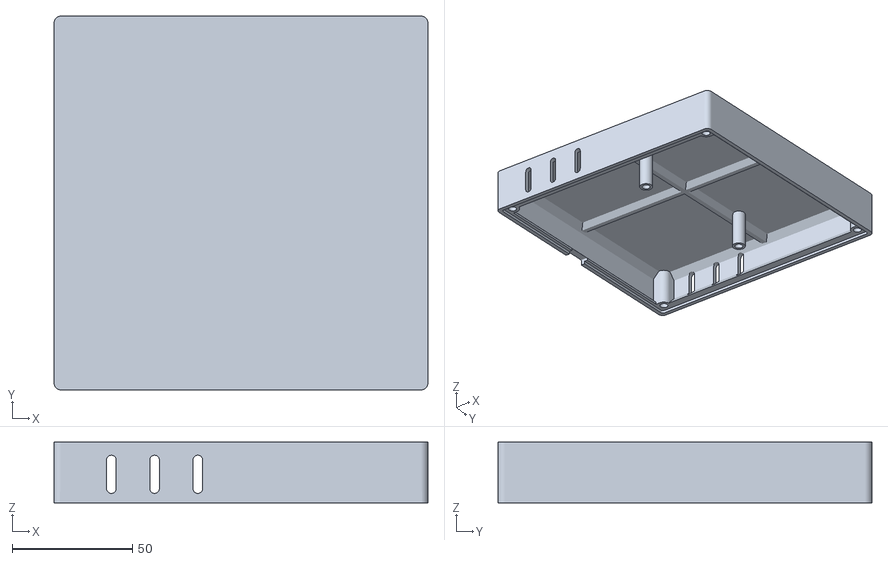
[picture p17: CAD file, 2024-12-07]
Hexa-Pi_Case/HexPi_1.1_botBody.stl
155.8 x 155.8 x 25.4

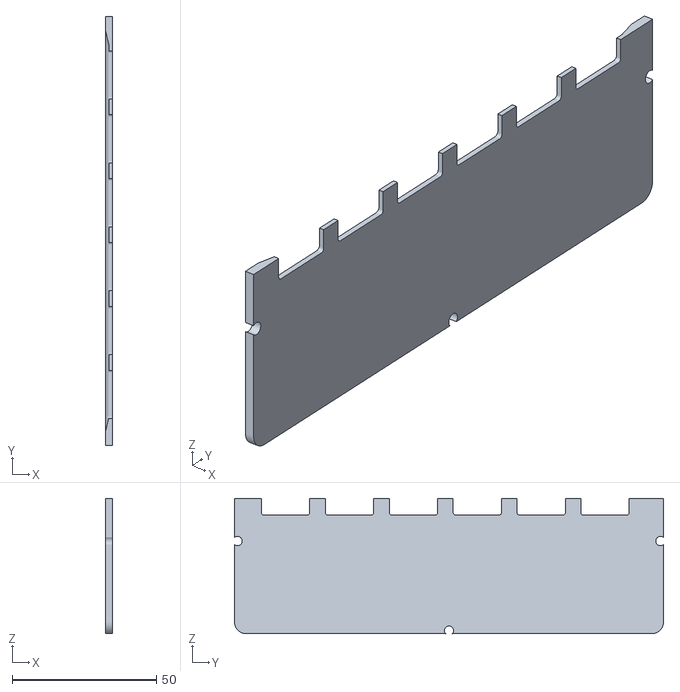
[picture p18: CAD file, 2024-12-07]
Hexa-Pi_Case/HexPi_1.1_frontPanelBody.stl
2.40 x 148.5 x 46.8

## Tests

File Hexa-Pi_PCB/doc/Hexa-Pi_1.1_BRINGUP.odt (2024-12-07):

Hexa-Pi_1.1 Bringup Procedure Board ID: ________

1. Label board serial number top and bottom ______
2. Solder power connector J19 ______
3. Plug into 12V supply and record supply voltages

5V0 = 5.00v–5.11v : 1V1 = 1.09v-1.15v : 3v3 = 3.34v-3.40v

Record voltages at indicated testpoints below:

5V0 : | 5V0 :
5V0 : | 1V1 :
5V0 : | 3V3 :
5V0 : | 5V0 :

4. If all within defined limits, remove power and continue
5. Solder 0Ω jumpers at R30, R72, R73 ______
6. Solder fan connectors at J11, J13 ______
7. Solder pin header at J12 (label EEWE) ______
8. Solder e-net jacks at U33, U34 ______
9. Solder dual-USB connector at J22 ______
10. Solder USB-C connector at J23 * ______
11. Solder Switch at U32 ______
12. Solder NeoPixel at D7 (careful on polarity) * ______
13. Solder DSI Connector at J20 * ______
14. Solder uSD Card Connector at J25 (back) * ______
15. Solder M.2 Connector at J24 (back) * ______
16. SSolder M.2 Nut at J24/2240 (back) ______
17. Program EEPROM for RTL8370 Ethernet Switch:
      A. Jumper EEWE to enable EEPROM Write ______
      B. Install a Pi4 in Module 5 location ______
      C. Power up the board ______
      D. Connect with either enet, wifi, or serial console ______
      E. Execute eeprom_write procedure. Verify success ______
      F. Power down. Remove EEWE jumper. Remove Pi4 ______
17. * Difficult to solder

Hexa-Pi_1.1_BRINGUP.odt October 22, 2024

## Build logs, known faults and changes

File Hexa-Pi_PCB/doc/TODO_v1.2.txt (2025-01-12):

Things-To-Do if another version (1.2?):

  - change 5ohm to 470ohm on NeoPixel Data - R75

  - Improve esd protection of emc2301 fan controller.
    Try esd diodes and series resistors?

  - Move j1-j6 0.3mm closer to top board edge
    0.2mm cu to board edge since this is routed, not v-scored
    0.1mm more - reduce size of MP pad

  - Move uSD,J19,J21 closer to bot board edge
    0.2mm CU to board edge since this edge is routed, not v-scored

  - Move M.2 connr and holes x-=0.5 to improve holddown screw clearance

  - Enlarge pads on usbc Connector - Avoid full soldermask on Top
    Use footprint Molex_xxxxxx_MOD - has small (>0) soldermask on front.

  - M.2 Connector - reduce size of thermal gaps - difficult to hand solder!
    Width to 0.13mm, Length to 0.4mm

  - DNP on I2C pullups - R98, R105. There are already pullups on the CM4.
    add a DNP pullup on TACH2 signal - near TACH1 pu?

  - Tighten up spacing on switch straps - ~1.0mm to mid, ~0.5mm right.

  - usb and enet switch - adjust thermal vias to minimize solder wicking

  - Consider switching usb switch USB2524 for SL2.1A
    Simpler, cheaper, bigger!

  - Try to avoid having to use layer In2 for SD_CMD from uSD.

  - Label +12 and GND near 12V fan connectors

  - Eliminate R115 - SD_DET is unused on uSD

  - Update footprint on NeoPixel - silkscreen only to show orientation better
  
  - Place (47uF) 0805 Caps near top power exit point for 5V to stop sags.

  - Include at least 1 USB3 port from Pi5CM - bottom smt connr?

  - flip pins on J18 iand label - keep power/gnd square/round consistent.

  - Move USB-C connector away from board edge by 1 mm.

  - Move power jack closer to board edge. (0.20 mm ?)

  - A few miscellaneous track/routing cleanups

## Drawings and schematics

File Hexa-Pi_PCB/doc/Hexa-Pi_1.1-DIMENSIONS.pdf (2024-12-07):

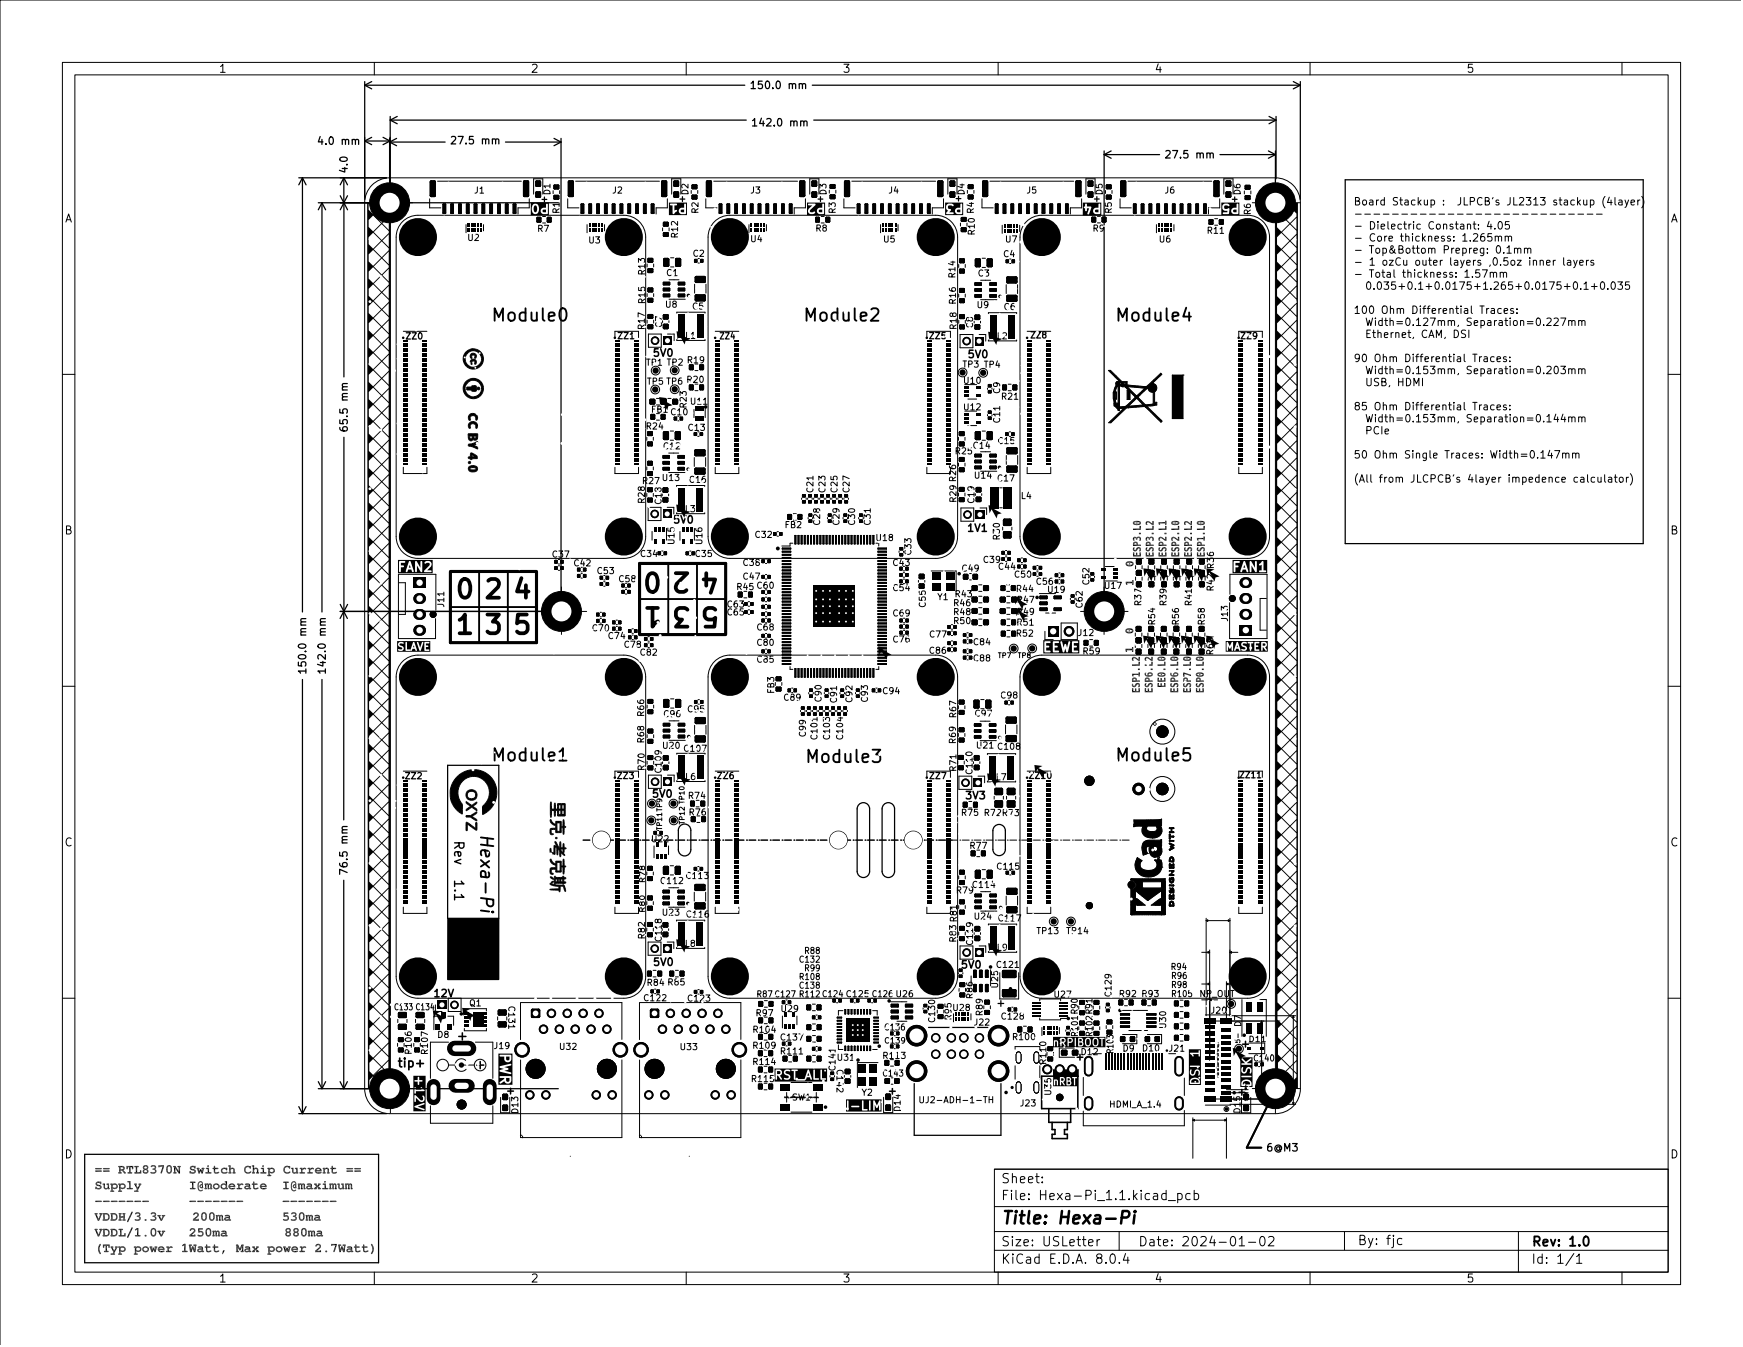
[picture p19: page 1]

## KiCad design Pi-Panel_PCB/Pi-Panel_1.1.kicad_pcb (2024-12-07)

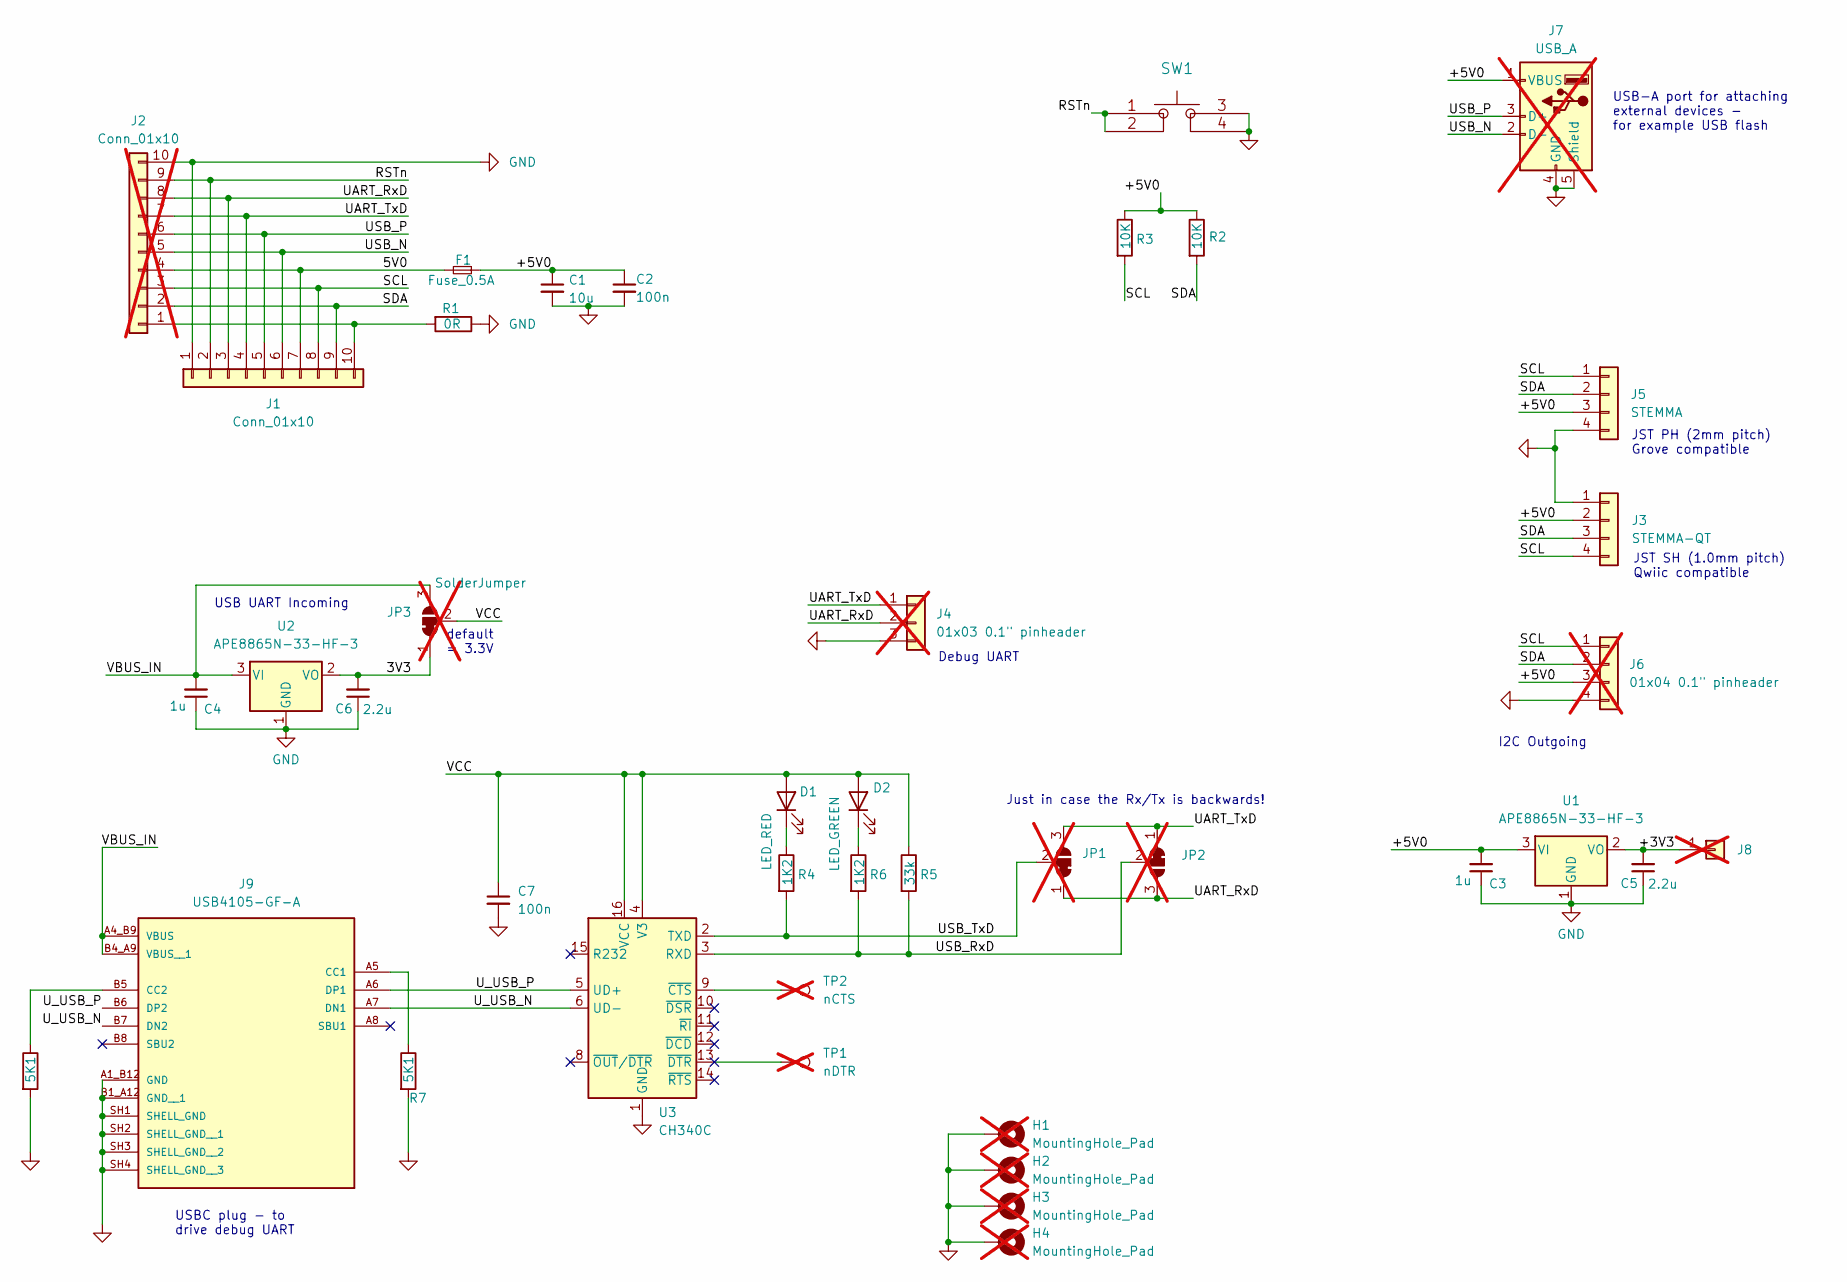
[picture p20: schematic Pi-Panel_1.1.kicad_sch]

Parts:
C1: 10u; C_0603_1608Metric; LCSC Part # C19702
C2, C7: 100n; C_0603_1608Metric; LCSC Part # C14663
C3, C4: 1u; C_0603_1608Metric; LCSC Part # C15849
C5, C6: 2.2u; C_0603_1608Metric; LCSC Part # C23630
D1: LED_RED; LED_0603_1608Metric; LCSC Part # C2286
D2: LED_GREEN; LED_0603_1608Metric; LCSC Part # C72038
F1: Fuse_0.5A; R_0603_1608Metric_Pad0.98x0.95mm_HandSolder; LCSC Part # C2960491
H1, H2, H3, H4: MountingHole_Pad; MountingHole_2.5mm_Pad_TopBottom; not fitted
J1: Conn_01x10; JST_GH_SM10B-GHS-TB_1x10-1MP_P1.25mm_Horizontal; Manuf Partno SM10B-GHS-TB; LCSC Part # C2683602
J2: Conn_01x10; PinHeader_1x10_P2.00mm_Vertical; not fitted
J3: STEMMA-QT; JST_SH_SM04B-SRSS-TB_1x04-1MP_P1.00mm_Horizontal; LCSC Part # C160404
J4: 01x03 0.1" pinheader; PinHeader_1x03_P2.54mm_Vertical; LCSC Part # TH; not fitted
J5: STEMMA; JST_PH_S4B-PH-SM4-TB_1x04-1MP_P2.00mm_Horizontal; LCSC Part # C265102
J6: 01x04 0.1" pinheader; PinHeader_1x04_P2.54mm_Vertical; LCSC Part # TH; not fitted
J7: USB_A; USB_A_Wuerth_614004134726_Horizontal; LCSC Part # TH; not fitted
J8: Conn_01x01; PinHeader_1x01_P2.54mm_Vertical; LCSC Part # TH; not fitted
J9: USB4105-GF-A; GCT_USB4105-GF-A; PARTREV B3; LCSC Part # C5184243
JP1, JP2, JP3: SolderJumper; SolderJumper-3_P1.3mm_Bridged12_RoundedPad1.0x1.5mm_NumberL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; not fitted
R1: 0R; R_0603_1608Metric_Pad0.98x0.95mm_HandSolder; LCSC Part # C21189
R2, R3: 10K; R_0603_1608Metric; LCSC Part # C25804
R4, R6: 1K2; R_0603_1608Metric; LCSC Part # C22765
R5: 33k; R_0603_1608Metric; LCSC Part # C4216
R7, R8: 5K1; R_0603_1608Metric; LCSC Part # C23186
SW1: pushButton-PTS647SM38SMTR2LFS; Part Description Tact Sw SPST-NO Top Actuated SMT 4.5mmX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; LCSC Part # C2689502
TP1: nDTR; TestPoint_Pad_1.0x1.0mm; not fitted
TP2: nCTS; TestPoint_Pad_1.0x1.0mm; not fitted
U1, U2: APE8865N-33-HF-3; SOT-23; LCSC Part # C296288
U3: CH340C; SOIC-16_3.9x9.9mm_P1.27mm; LCSC Part # C7464026

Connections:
/3V3: C6.2, JP3.1 (A), U2.2 (VO)
/5V0: F1.2, J1.7, J2.4
/+3V3: C5.2, J8.1, U1.2 (VO)
/+5V0: C1.1, C2.1, C3.2, F1.1, J3.2, J5.3, J6.3, J7.1 (VBUS), R2.1, R3.1, U1.3 (VI)
/RSTn: J1.2, J2.9, SW1.1, SW1.2
/SCL: J1.8, J2.3, J3.4, J5.1, J6.1, R3.2
/SDA: J1.9, J2.2, J3.3, J5.2, J6.2, R2.2
/UART_RxD: J1.3, J2.8, J4.2, JP1.1 (A), JP2.3 (B)
/UART_TxD: J1.4, J2.7, J4.1, JP1.3 (B), JP2.1 (A)
/USB_N: J1.6, J2.5, J7.2 (D-)
/USB_P: J1.5, J2.6, J7.3 (D+)
/USB_RxD: JP2.2 (C), R5.2, R6.2, U3.3 (RXD)
/USB_TxD: JP1.2 (C), R4.2, U3.2 (TXD)
/U_USB_N: J9.A7 (DN1), J9.B7 (DN2), U3.6 (UD-)
/U_USB_P: J9.A6 (DP1), J9.B6 (DP2), U3.5 (UD+)
/VBUS_IN: C4.2, J9.A4_B9 (VBUS), J9.B4_A9 (VBUS__1), JP3.3 (B), U2.3 (VI)
/VCC: C7.1, D1.2 (A), D2.2 (A), JP3.2 (C), R5.1, U3.4 (V3), U3.16 (VCC)
GND: C1.2, C2.2, C3.1, C4.1, C5.1, C6.1, C7.2, H1.1, H2.1, H3.1, H4.1, J1.1, J2.10, J3.1, J4.3, J5.4, J6.4, J7.4 (GND), J7.5 (Shield), J9.A1_B12 (GND), J9.B1_A12 (GND__1), J9.SH1 (SHELL_GND), J9.SH2 (SHELL_GND__1), J9.SH3 (SHELL_GND__2), J9.SH4 (SHELL_GND__3), R1.1, R7.2, R8.2, SW1.3, SW1.4, U1.1 (GND), U2.1 (GND), U3.1 (GND)
unnamed: D1.1 (K), R4.1
unnamed: D2.1 (K), R6.1
unnamed: J1.10, J2.1, R1.2
unnamed: J9.A5 (CC1), R7.1
unnamed: J9.B5 (CC2), R8.1
unnamed: TP2.1, U3.9 (~CTS)

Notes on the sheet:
I2C Outgoing
JST PH (2mm pitch) Grove compatible
USB-A port for attaching external devices - for example USB flash
Debug UART
USB UART Incoming
JST SH (1.0mm pitch) Qwiic compatible
default = 3.3V
USBC plug - to drive debug UART
Just in case the Rx/Tx is backwards!

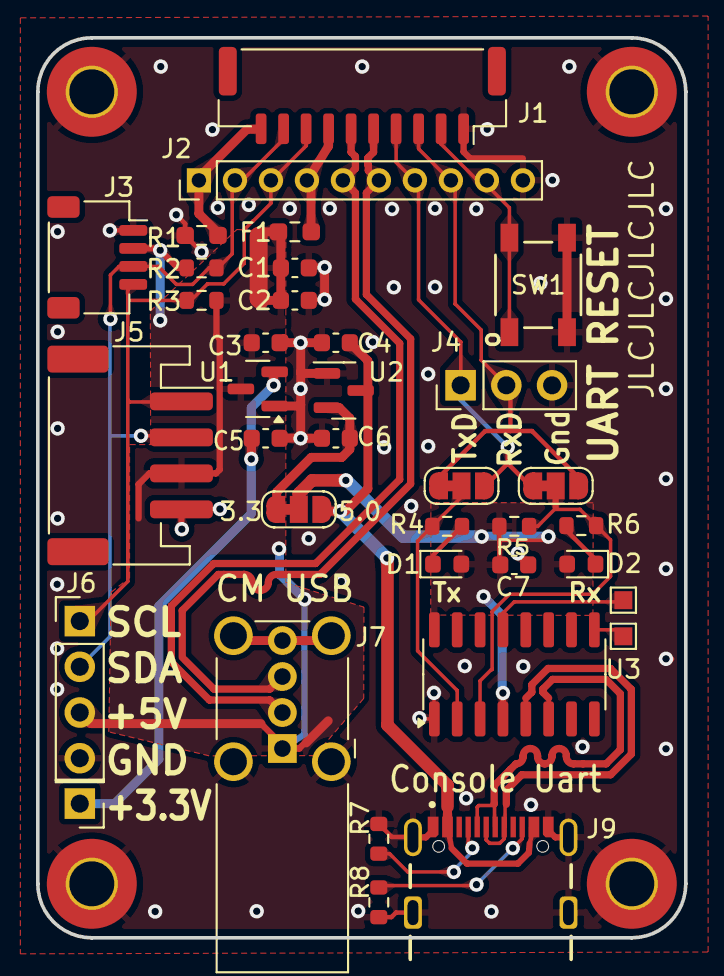
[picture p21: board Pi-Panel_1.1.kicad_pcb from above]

Board: 2 copper layers, 36.0 x 50.0 mm, 40 parts (0 on the bottom side), 24 nets.

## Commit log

2025-03-24 Improved Case Picture
2025-03-24 Better Case Picture

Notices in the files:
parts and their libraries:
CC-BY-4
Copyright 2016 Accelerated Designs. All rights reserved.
